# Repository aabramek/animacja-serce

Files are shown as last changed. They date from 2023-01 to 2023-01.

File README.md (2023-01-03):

# animacja-serce
Płytka z ledami ułożonymi w kształ serca
do wyświetlania animacji

## Obsługa
Ustawienie parametrów jest realizowane przez ustawienia

+ Wyboru animacji

+ Czasu między kolejnymi krokami animacji

+ Jasności diod

Krótkie przyciśnięcie przycisku zmienia wartość wybranego ustawienia np. kolejna animacja lub zwiększenie jasności
Kierunek zmian jest w jedną stronę, aby przejść na początek trzeba przejść przez wszystkie wartości

Długie przyciśnięcie przycisku przełącza się między ustawieniami

## To do:

Zmiana formatu animacji z wbudowanych w program funkcji na kod możliwy do zapisania w pamięci np. EEPROM i późniejszego 
załadowania i zinterpretowania przez program

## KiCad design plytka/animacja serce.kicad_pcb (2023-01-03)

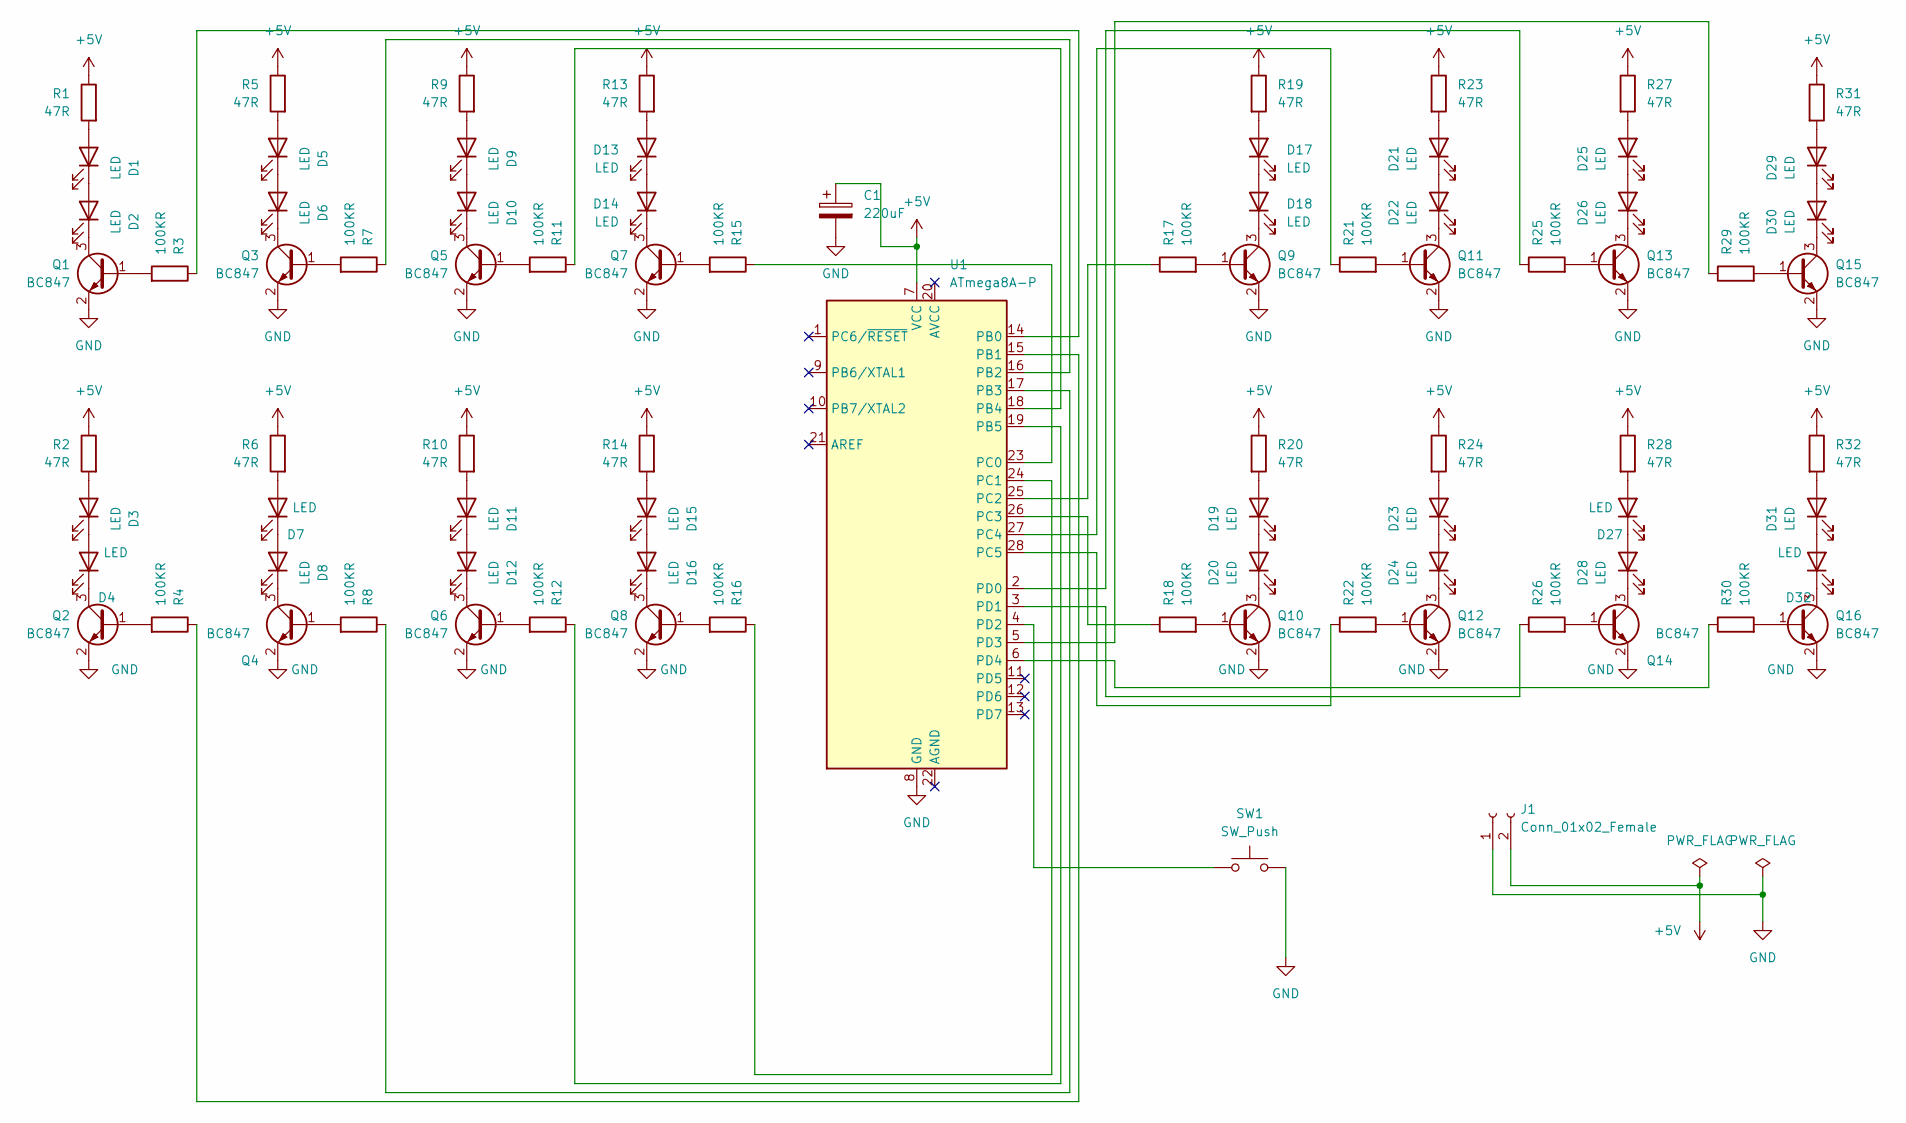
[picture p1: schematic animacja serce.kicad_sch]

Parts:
C1: 220uF; CP_Radial_D6.3mm_P2.50mm
D1, D2, D3, D4, D5, D6, D7, D8, D9, D10, D11, D12, D13, D14, D15, D16, D17, D18, D19, D20, D21, D22, D23, D24, D25, D26, D27, D28, D29, D30, D31, D32: LED; LED_1210_3225Metric_Pad1.42x2.65mm_HandSolder
J1: Conn_01x02_Female; SolderWire-2.5sqmm_1x02_P7.2mm_D2.4mm_OD3.6mm
Q1, Q2, Q3, Q4, Q5, Q6, Q7, Q8, Q9, Q10, Q11, Q12, Q13, Q14, Q15, Q16: BC847; SOT-23
R1, R2, R5, R6, R9, R10, R13, R14, R19, R20, R23, R24, R27, R28, R31, R32: 47R; R_1206_3216Metric_Pad1.30x1.75mm_HandSolder
R3, R4, R7, R8, R11, R12, R15, R16, R17, R18, R21, R22, R25, R26, R29, R30: 100KR; R_1206_3216Metric_Pad1.30x1.75mm_HandSolder
SW1: SW_Push; R_Axial_DIN0207_L6.3mm_D2.5mm_P5.08mm_Vertical
U1: ATmega8A-P; DIP-28_W7.62mm

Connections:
+5V: C1.1, J1.2, R1.1, R2.1, R5.1, R6.1, R9.1, R10.1, R13.1, R14.1, R19.1, R20.1, R23.1, R24.1, R27.1, R28.1, R31.1, R32.1, U1.7 (VCC)
GND: C1.2, J1.1, Q1.2 (E), Q2.2 (E), Q3.2 (E), Q4.2 (E), Q5.2 (E), Q6.2 (E), Q7.2 (E), Q8.2 (E), Q9.2 (E), Q10.2 (E), Q11.2 (E), Q12.2 (E), Q13.2 (E), Q14.2 (E), Q15.2 (E), Q16.2 (E), SW1.2, U1.8 (GND)
unnamed: D1.1 (K), D2.2 (A)
unnamed: D1.2 (A), R1.2
unnamed: D2.1 (K), Q1.3 (C)
unnamed: D3.1 (K), D4.2 (A)
unnamed: D3.2 (A), R2.2
unnamed: D4.1 (K), Q2.3 (C)
unnamed: D5.1 (K), D6.2 (A)
unnamed: D5.2 (A), R5.2
unnamed: D6.1 (K), Q3.3 (C)
unnamed: D7.1 (K), D8.2 (A)
unnamed: D7.2 (A), R6.2
unnamed: D8.1 (K), Q4.3 (C)
unnamed: D9.2 (A), R9.2
unnamed: D10.1 (K), Q5.3 (C)
unnamed: D9.1 (K), D10.2 (A)
unnamed: D11.1 (K), D12.2 (A)
unnamed: D11.2 (A), R10.2
unnamed: D12.1 (K), Q6.3 (C)
unnamed: D13.1 (K), D14.2 (A)
unnamed: D13.2 (A), R13.2
unnamed: D14.1 (K), Q7.3 (C)
unnamed: D15.1 (K), D16.2 (A)
unnamed: D15.2 (A), R14.2
unnamed: D16.1 (K), Q8.3 (C)
unnamed: D17.1 (K), D18.2 (A)
unnamed: D17.2 (A), R19.2
unnamed: D18.1 (K), Q9.3 (C)
unnamed: D19.1 (K), D20.2 (A)
unnamed: D19.2 (A), R20.2
unnamed: D20.1 (K), Q10.3 (C)
unnamed: D21.1 (K), D22.2 (A)
unnamed: D21.2 (A), R23.2
unnamed: D22.1 (K), Q11.3 (C)
unnamed: D23.1 (K), D24.2 (A)
unnamed: D23.2 (A), R24.2
unnamed: D24.1 (K), Q12.3 (C)
unnamed: D25.1 (K), D26.2 (A)
unnamed: D25.2 (A), R27.2
unnamed: D26.1 (K), Q13.3 (C)
unnamed: D27.1 (K), D28.2 (A)
unnamed: D27.2 (A), R28.2
unnamed: D28.1 (K), Q14.3 (C)
unnamed: D29.1 (K), D30.2 (A)
unnamed: D29.2 (A), R31.2
unnamed: D30.1 (K), Q15.3 (C)
unnamed: D31.1 (K), D32.2 (A)
unnamed: D31.2 (A), R32.2
unnamed: D32.1 (K), Q16.3 (C)
unnamed: Q1.1 (B), R3.2
unnamed: Q2.1 (B), R4.2
unnamed: Q3.1 (B), R7.2
unnamed: Q4.1 (B), R8.2
unnamed: Q5.1 (B), R11.2
unnamed: Q6.1 (B), R12.2
unnamed: Q7.1 (B), R15.2
unnamed: Q8.1 (B), R16.2
unnamed: Q9.1 (B), R17.2
unnamed: Q10.1 (B), R18.2
unnamed: Q11.1 (B), R21.2
unnamed: Q12.1 (B), R22.2
unnamed: Q13.1 (B), R25.2
unnamed: Q14.1 (B), R26.2
unnamed: Q15.1 (B), R29.2
unnamed: Q16.1 (B), R30.2
unnamed: R3.1, U1.14 (PB0)
unnamed: R4.1, U1.15 (PB1)
unnamed: R7.1, U1.16 (PB2)
unnamed: R8.1, U1.17 (PB3)
unnamed: R11.1, U1.18 (PB4)
unnamed: R12.1, U1.19 (PB5)
unnamed: R15.1, U1.23 (PC0)
unnamed: R16.1, U1.24 (PC1)
unnamed: R17.1, U1.25 (PC2)
unnamed: R18.1, U1.26 (PC3)
unnamed: R21.1, U1.27 (PC4)
unnamed: R22.1, U1.28 (PC5)
unnamed: R25.1, U1.2 (PD0)
unnamed: R26.1, U1.3 (PD1)
unnamed: R29.1, U1.5 (PD3)
unnamed: R30.1, U1.6 (PD4)
unnamed: SW1.1, U1.4 (PD2)

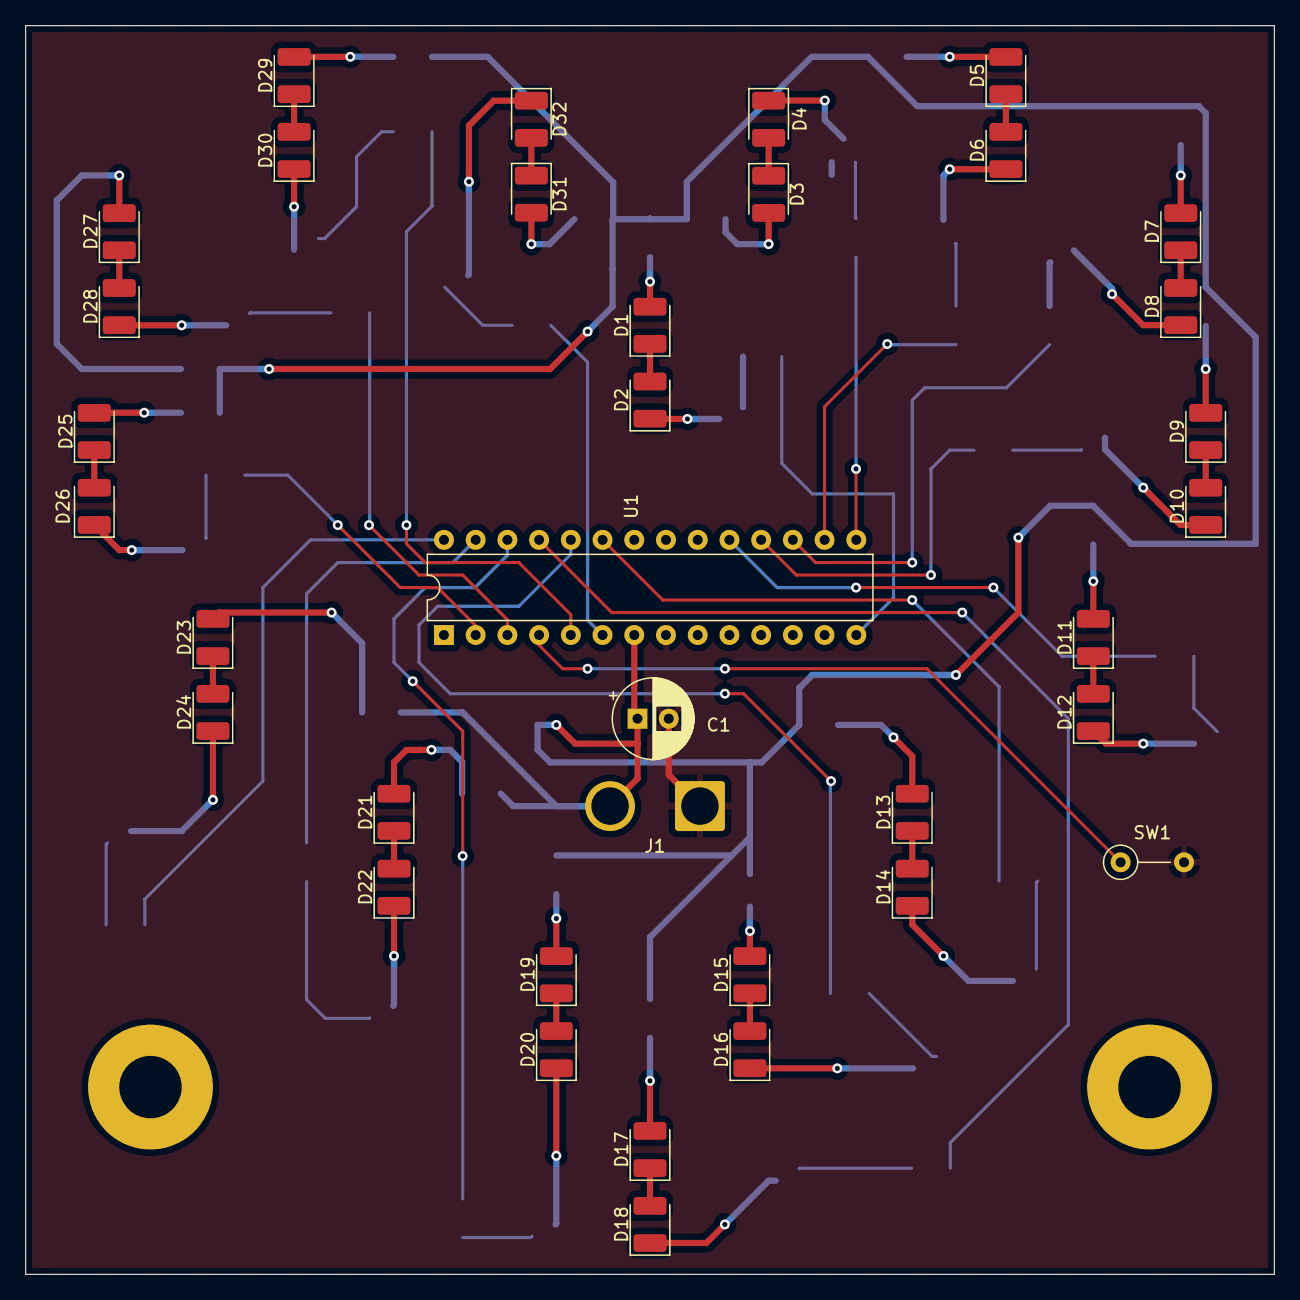
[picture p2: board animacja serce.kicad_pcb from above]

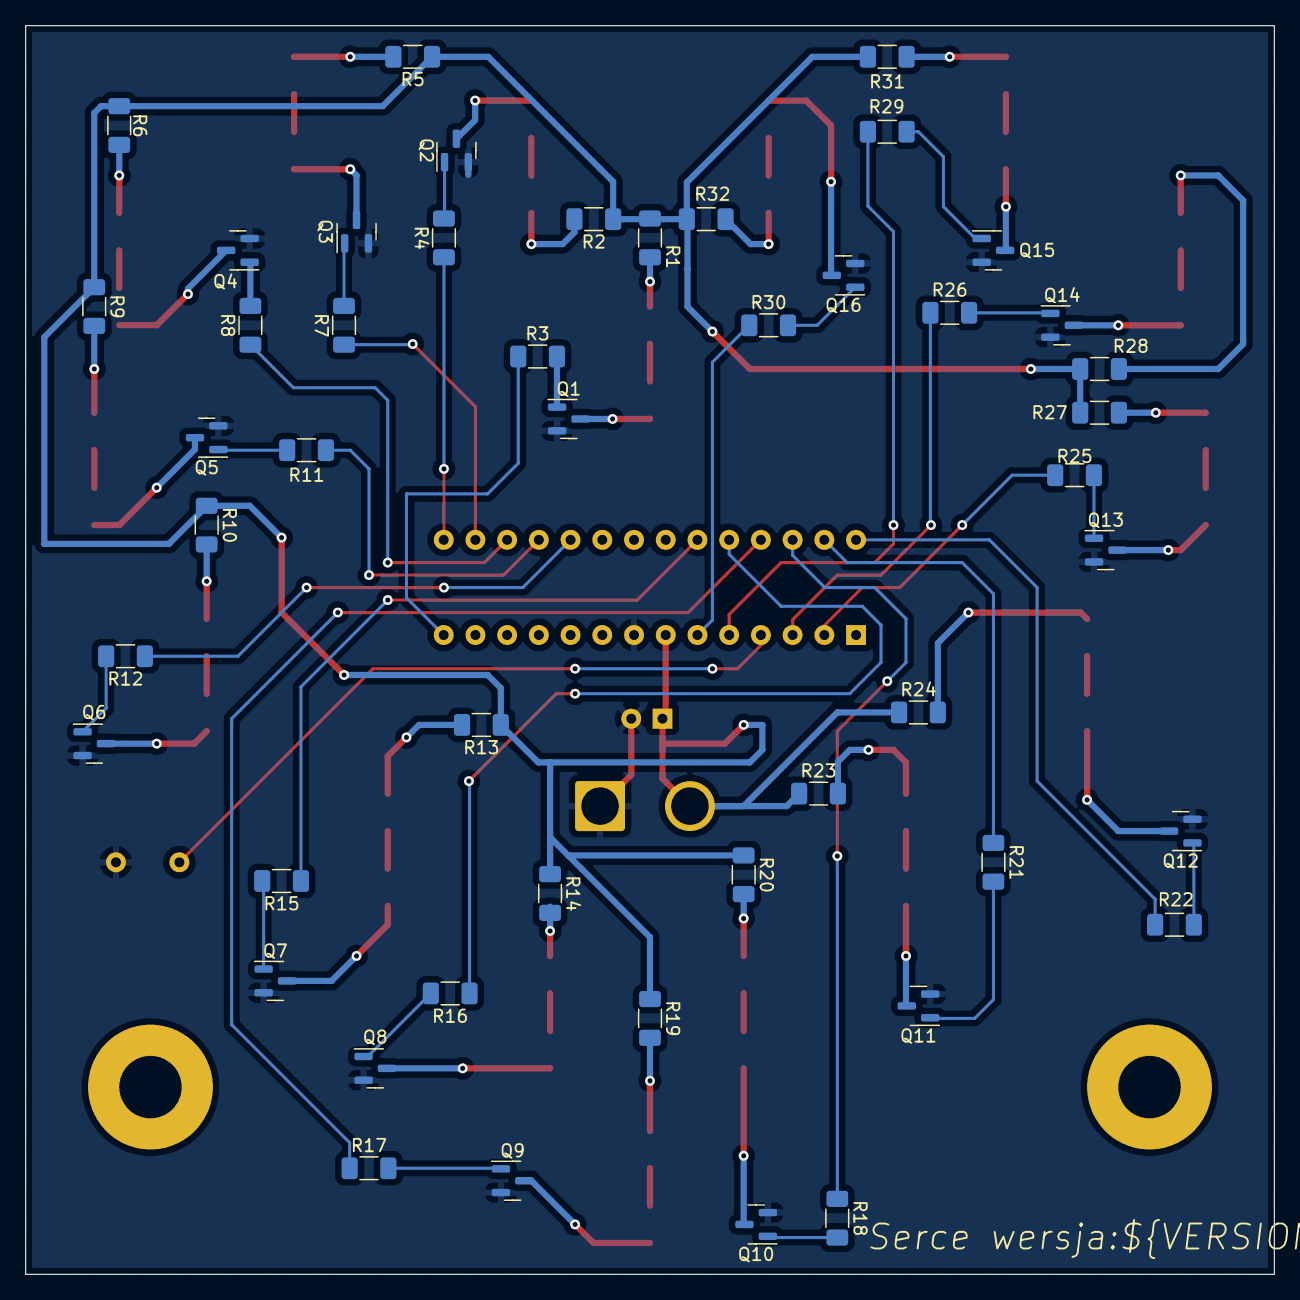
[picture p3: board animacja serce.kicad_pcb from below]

Board: 2 copper layers, 100.0 x 100.0 mm, 84 parts (48 on the bottom side), 83 nets.

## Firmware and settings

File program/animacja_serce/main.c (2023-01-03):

#define F_CPU 100000

#include <avr/io.h>
#include <avr/interrupt.h>
#include <util/delay.h>

#define N_ANIMATIONS 6
#define N_OPIONS 3
#define N_LEDS 16
#define ANIMATION_UPDATE_MAX 120
#define ANIMATION_UPDATE_STEP 12
#define BRIGHTNESS_UPDATE_STEP 20

volatile uint8_t* led_port[N_LEDS];
volatile uint8_t port_buffer[3] = {0, 0, 0};	
uint8_t led_mask[N_LEDS];

uint8_t button_pressed = 0;
uint8_t option = 0;

uint8_t animation = 0;
volatile uint8_t animation_step = 0;
uint8_t animation_update = ANIMATION_UPDATE_STEP;
uint8_t animation_t = 0;
const uint8_t animation_steps[N_ANIMATIONS] = {12, 2, 12, 6, 0, 20/*, 19*/};
	
void set(uint8_t pos);
void clear(uint8_t pos);
void toggle(uint8_t pos);

void anim0(void);
void anim1(void);
void anim2(void);
void anim3(void);
void anim4(void);
void anim5(void);
//void anim6(void);

void (*animations[N_ANIMATIONS])(void) = {anim0, anim1, anim2, anim3, anim4, anim5/*, anim6*/};

int main(void)
{	
	for (uint8_t i = 0; i < 6; ++i)
	{
		led_port[i] = &port_buffer[0];
		led_mask[i] = 1 << i;
	}
	for (uint8_t i = 6; i < 12; ++i)
	{
		led_port[i] = &port_buffer[1];
		led_mask[i] = 1 << (i - 6);
	}
	for (uint8_t i = 12; i < 16; ++i)
	{
		led_port[i] = &port_buffer[2];
    }
	led_mask[12] = 1 << 0;
	led_mask[13] = 1 << 1;
	led_mask[14] = 1 << 3;	
	led_mask[15] = 1 << 4;			
	
	DDRB |= 0x3F;
	DDRC |= 0x3F;
	DDRD |= 0x1B;
	
	PORTB &= ~0x3F;
	PORTC &= ~0x3F;
	PORTD &= ~0x1B;
	
	DDRD &= ~(1 << PORTD2);
	PORTD |= (1 << DDRD2);
	
	// F_CPU = 1 000 000 Hz
	// T = 16.384 ms
	TIFR |= (1 << TOV0);
	TIMSK |= (1 << TOIE0);
	TCCR0 = (1 << CS01) | (1 << CS00);
	
	// f = 1 000 000 Hz
	TIFR |= (1 << OCF2) | (1 << TOV2);
	TIMSK |= (1 << OCIE2) | (1 << TOIE2);
	OCR2 = 20;
	TCCR2 = (1 << WGM21) | (1 << WGM20) | (1 << CS20);
	
	sei();	
	
	while (1) 
    {

    }
}


ISR(TIMER0_OVF_vect)
{
	if ((PIND & (1 << PIND2)) == 0)
	{
		if (button_pressed < 255)
		{
			++button_pressed;
		}
	}
	else
	{
		// button pressed for long time
		if (button_pressed > 48)
		{
			++option;
			if (option == N_OPIONS)
			{
				option = 0;
			}
		}
		// button pressed for short time
		else if (button_pressed > 2)
		{
			if (option == 0)
			{
				++animation;
				if (animation == N_ANIMATIONS)
				{
					animation = 0;
				}
				animation_step = 0;
				port_buffer[0] &= 0xC0;
				port_buffer[1] &= 0xC0;
				port_buffer[2] &= 0xE4;
			}
			else if (option == 1)
			{
				animation_update += ANIMATION_UPDATE_STEP;
				if (animation_update == ANIMATION_UPDATE_MAX)
				{
					animation_update = ANIMATION_UPDATE_STEP;
				}
			}
			else if (option == 2)
			{
				uint8_t ocr = OCR2;
				if (255 - BRIGHTNESS_UPDATE_STEP < ocr)
				{
					ocr = BRIGHTNESS_UPDATE_STEP;
				}
				else
				{
					ocr += BRIGHTNESS_UPDATE_STEP;
				}
				OCR2 = ocr;
			}
		}
		button_pressed = 0;
	}
	
	++animation_t;
	if (animation_t >= animation_update)
	{
		animation_t = 0;
		(*animations[animation])();
		++animation_step;
		if (animation_step == animation_steps[animation])
		{
			animation_step = 0;
		}
	}
}

ISR(TIMER2_COMP_vect)
{
	PORTB &= 0xC0;
	PORTC &= 0xC0;
	PORTD &= 0xE4;
}

ISR(TIMER2_OVF_vect)
{
	PORTB |= port_buffer[0];
	PORTC |= port_buffer[1];
	PORTD |= port_buffer[2];
}

void set(uint8_t pos)
{
	*led_port[pos] |= led_mask[pos];
}

void clear(uint8_t pos)
{
	*led_port[pos] &= ~led_mask[pos];
}

void toggle(uint8_t pos)
{
	*led_port[pos] ^= led_mask[pos];
}

void anim0(void)
{
	if (animation_step >= 9)
	{
		return;
	}
	if (animation_step != 0 && animation_step != 8)
	{
		toggle(16 - animation_step);
	}
	toggle(animation_step);
}

void anim1(void)
{
	port_buffer[0] ^= 0x3F;
	port_buffer[1] ^= 0x3F;
	port_buffer[2] ^= 0x3B;
}

void anim2(void)
{
	if (animation_step >= 8)
	{
		return;
	}
	toggle(animation_step);
	toggle(animation_step + 8);
}

void anim3(void)
{
	if (animation_step == 5)
		return;
	if (animation_step == 0 || animation_step == 4)
	{
		toggle(animation_step);
		toggle(animation_step + 8);
	}
	else
	{
		toggle(animation_step);
		toggle(8 - animation_step);
		toggle(animation_step + 8);
		toggle(16 - animation_step);
	}
}

void anim4(void)
{
	port_buffer[0] |= 0x3F;
	port_buffer[1] |= 0x3F;
	port_buffer[2] |= 0x3B;
}

void anim5(void)
{
	if (animation_step >= 17)
	{
		return;
	}
	toggle(animation_step);
}

/*void anim6(void)
{
	if (animation_step >= 17)
	{
		port_buffer[0] &= 0xC0;
		port_buffer[1] &= 0xC0;
		port_buffer[2] &= 0xE4;
		return;
	}
	uint8_t t = animation_step << 1;
	if (animation_step > 8)
	{
		t -= 17;
	}
	set(t);
}*/
